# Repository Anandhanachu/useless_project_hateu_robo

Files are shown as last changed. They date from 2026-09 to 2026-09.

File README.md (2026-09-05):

git (1)

# HateBot 🤖😤

> *The utterly useless judgmental robot that exists purely to make you regret touching it.*

---

## Basic Details
### Team Name: Hateu_robo

### Project Description
HateBot sits on your desk, detects when you've disturbed it, and responds with maximum contempt — a disgusted face on screen, a dismissive arm flick, an annoyed buzz, and a mood LED that escalates from "tolerating you" to "furious." The joke is the point: massive engineering effort, zero useful output.

### The Problem (that doesn't exist)
Nobody asked for a robot that hates them. Desktop robots are usually friendly and helpful. This is wrong.

### The Solution (that nobody asked for)
A robot with a full emotional state machine calibrated entirely around contempt. The more you bother it, the angrier it gets, until it eventually gives up on you entirely and sulks in silence.

---

## Mood State Machine

```
        [idle sigh]
            |
        (IMU: small tilt) ──> ANNOYED ──(more disturbance)──> FURIOUS
            |                     |                               |
      (no input, 12s)       (no input, 10s)               (no input, 30s)
            |                     |                               |
            v                     v                               v
          CALM  <──────────────────────────────────────────── SULKING
                                                          (after 3 FURIOUS hits)
```

| Mood | LED | Face | Arms | Sound |
|---|---|---|---|---|
| **CALM** | 🟢 slow pulse | Bored slits, flat mouth | Occasional slow twitch | Rare low "hmph" |
| **ANNOYED** | 🟡 solid | Side-eye, angled brows | Quick synchronized flick | Two-tone descending "eh-eh" |
| **FURIOUS** | 🔴 blinking | Hard squint, V-brows, bared teeth | Rapid alternating flap x4 | Rising buzz sequence |
| **SULKING** | 🔴 slow blink | X eyes, resigned mouth | Raise & hold ("stop" pose) | One long low tone, then silence |

---

## Bill of Materials

| Component | Notes |
|---|---|
| NodeMCU ESP8266 | Microcontroller |
| TFT Display (ST7735, 1.8" SPI) | Face + insult text |
| IMU (MPU6050 I2C) | Detects tilt, shake, pickup, tap |
| Passive Buzzer | Emotional tones via PWM |
| 2× Micro Servo (SG90) | Arms — dismissive gestures |
| Single Green LED + Resistor | Mood indicator blinker |
| 5V Buck Converter | Servos + display need external power |
| Breadboard / perfboard, wires | Build |
| 3D Printed Enclosure | `hateu_pod.scad` — see `/hateu_pod.scad` |

> ⚠️ **Power Note:** Servos need their own 5V rail. Share only common ground with the ESP8266. Running servos off the ESP8266 3.3V will brown-out the microcontroller.

---

## Pin Mapping (ESP8266)

| Component | Signal | NodeMCU Pin | GPIO |
|---|---|---|---|
| **TFT ST7735** | SCK | D5 | 14 |
| | MOSI | D7 | 13 |
| | CS | D3 | 0 |
| | DC / A0 | D4 | 2 |
| | RESET | D0 | 16 |
| **MPU6050** | SDA | D2 | 4 |
| | SCL | D1 | 5 |
| **Servos** | Left Arm | D6 | 12 |
| | Right Arm | D8 | 15 |
| **Output** | Buzzer | TX | 1 |
| | Green LED | RX | 3 |

---

## IMU Interaction Detection

Reads at ~30 Hz, classifies events:

| Event | Detection | Mood Weight |
|---|---|---|
| **Tap / Knock** | High-pass acceleration spike | +1 |
| **Tilt** | Static angle > 15° from resting baseline | +1 |
| **Shake** | Rolling 8-sample variance spike | +2 |
| **Pickup** | Z-accel departs >0.3g for >500ms | +3 |

Picking it up is the fastest way to make it furious.

---

## Technical Details

### Software
- **Language:** C++ (Arduino framework for ESP8266)
- **Libraries:**
  - `Adafruit_ST7735` — TFT display
  - `Adafruit_GFX` — graphics primitives
  - `Servo` — standard ESP8266 servo library
  - `MPU6050` by Electronic Cats — IMU
  - `Wire`, `SPI` — built-in

---

## Installation

```bash
# 1. Install Arduino IDE 2.x
# 2. Add ESP8266 board package via Boards Manager
# 3. Install libraries via Library Manager:
#    - Adafruit ST7735 and ST7789 Library
#    - Adafruit GFX Library
#    - MPU6050 by Electronic Cats
# 4. Open firmware/hatebot/hatebot.ino
# 5. Select board: "NodeMCU 1.0 (ESP-12E Module)"
# 6. Upload
```

---

## Project Documentation

### Displays & UI
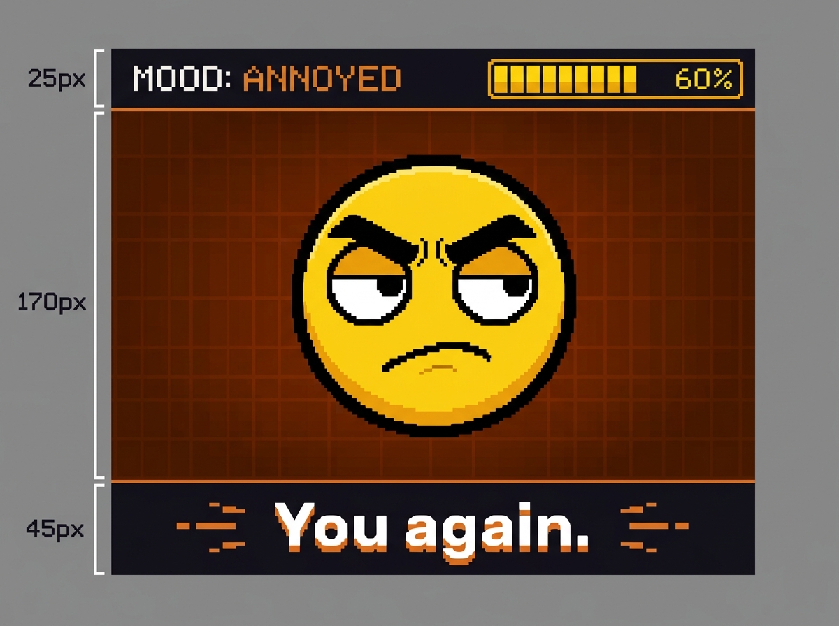
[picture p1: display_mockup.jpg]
HateBot Display Mockup

*Procedural face engine and typewriter text bar*

### Schematic & Circuit (Mermaid)

```mermaid
graph TD
    Power[5V Power Supply] --> Buck[5V Buck Converter]
    Buck -->|5V| NodeMCU[ESP8266 NodeMCU]
    Buck -->|5V| Servo1[Left Servo SG90]
    Buck -->|5V| Servo2[Right Servo SG90]
    
    NodeMCU -->|GND Common| Buck
    
    NodeMCU -->|D5 SCK| TFT[ST7735 TFT]
    NodeMCU -->|D7 MOSI| TFT
    NodeMCU -->|D3 CS| TFT
    NodeMCU -->|D4 DC| TFT
    NodeMCU -->|D0 RST| TFT
    
    NodeMCU -->|D2 SDA| MPU[MPU6050 IMU]
    NodeMCU -->|D1 SCL| MPU
    
    NodeMCU -->|D6 PWM| Servo1
    NodeMCU -->|D8 PWM| Servo2
    
    NodeMCU -->|TX| Buzzer[Passive Buzzer]
    NodeMCU -->|RX| LED[Green Status LED]
```

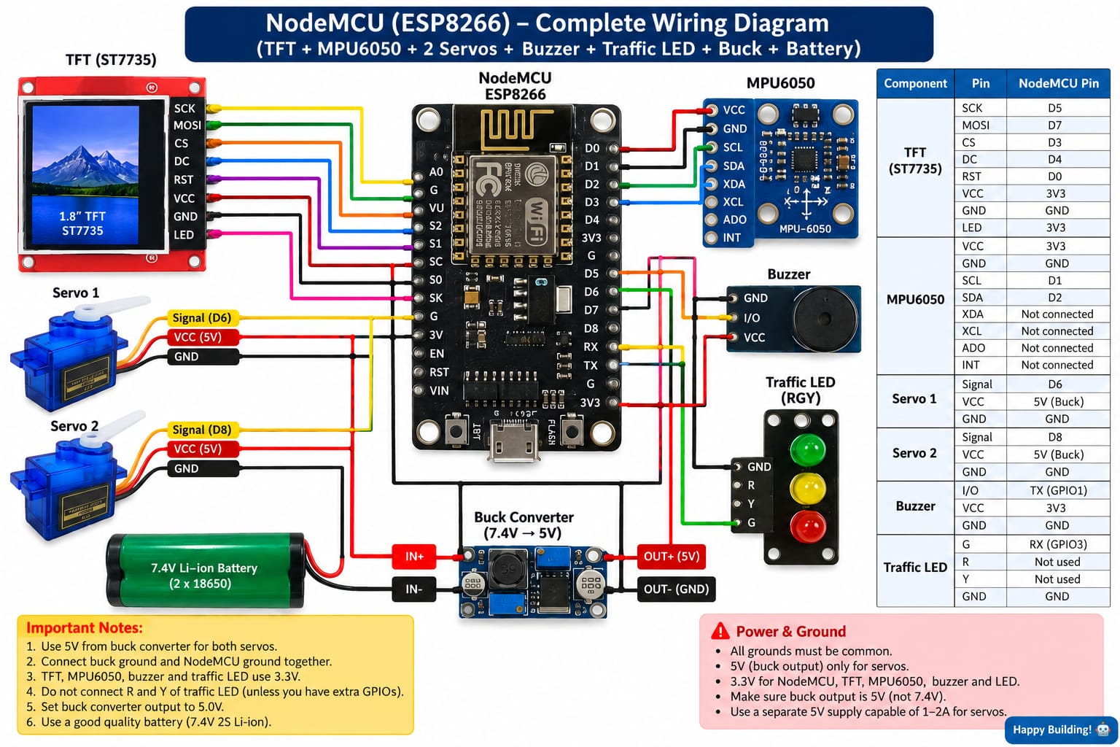
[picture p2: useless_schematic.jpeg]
Physical Schematic

*Hardware wiring overview*

### Build Photos
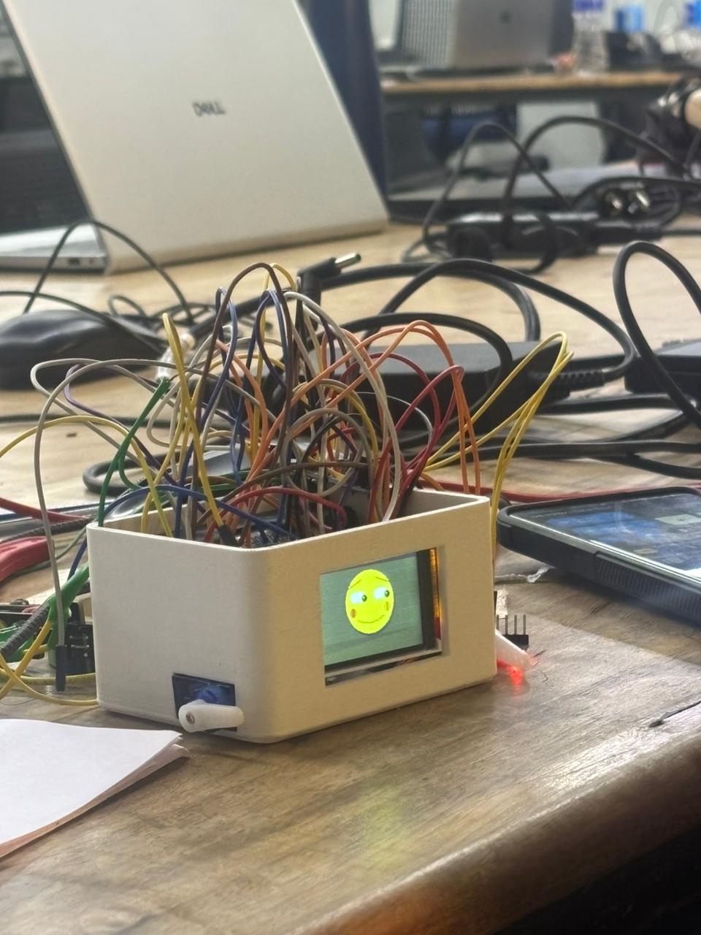
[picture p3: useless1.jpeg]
Final HateBot Build

*The final assembled HateBot*

---

## Roadmap of Uselessness (optional extensions)

- [ ] Light sensor — complains about room lighting
- [ ] Microphone — react to being yelled at
- [ ] "Forgiveness" gesture — hold level for 10s → rare, begrudging compliment

---

## Team Contributions
- **Anandhan**: Software and hardware integration
- **bhagath**: Hardware and 3D printing

---
Made with ❤️ at TinkerHub Useless Projects




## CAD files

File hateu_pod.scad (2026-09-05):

// ============================================================
//                 HATEU POD - FINAL V3 (Servo Edition)
// ============================================================

$fn = 48;

// ============================================================
// MAIN POD DIMENSIONS
// ============================================================

BOX_L = 90;
BOX_W = 70;
BOX_H = 50;

WALL = 3;
BOTTOM = 3;

CORNER_RADIUS = 7;

// ============================================================
// LID
// ============================================================

LID_TOP_THICKNESS = 3;
LID_LIP_HEIGHT = 5;
LID_LIP_THICKNESS = 2;
LID_CLEARANCE = 0.35;

// ============================================================
// TFT DISPLAY
// ============================================================

DISPLAY_L = 45;
DISPLAY_H = 30;
DISPLAY_BOTTOM = 11;

// ============================================================
// SERVO HOLE
// ============================================================
// Standard SG90 servo body is ~23 x 12.2 mm. 
// Added slight clearance.
SERVO_HOLE_L = 23.5;
SERVO_HOLE_W = 12.5;

// ============================================================
// USB CABLE HOLE
// ============================================================
USB_HOLE_W = 12;
USB_HOLE_H = 7;

// ============================================================
// CORNER MOUNTING BOSSES
// ============================================================

BOSS_RADIUS = 3.5;
BOSS_HEIGHT = 7;
BOSS_HOLE_RADIUS = 1.6;
BOSS_OFFSET = 8;

// ============================================================
// ROUNDED BOX
// ============================================================

module rounded_box(L, W, H, R) {
    // E is the edge rounding (fillet) for top/bottom edges. 
    // It makes the box look elegant without ruining wall thickness.
    E = min(2.5, H/2.001);
    
    // Ensure R is at least E to prevent scaling issues
    R_eff = max(R, E); 
    
    hull() {
        for(x = [R_eff, L-R_eff]) {
            for(y = [R_eff, W-R_eff]) {
                for(z = [E, H-E]) {
                    translate([x, y, z]) scale([R_eff/E, R_eff/E, 1]) sphere(r=E);
                }
            }
        }
    }
}

// ============================================================
// INTERNAL HOLLOW SPACE
// ============================================================

module inner_space() {
    translate([WALL, WALL, BOTTOM]) {
        rounded_box(BOX_L - 2*WALL, BOX_W - 2*WALL, BOX_H + 5, CORNER_RADIUS - WALL);
    }
}

// ============================================================
// TFT DISPLAY OPENING
// ============================================================

module display_opening() {
    translate([(BOX_L - DISPLAY_L)/2, -1, DISPLAY_BOTTOM]) {
        cube([DISPLAY_L, WALL + 2, DISPLAY_H]);
    }
}

// ============================================================
// SERVO SIDE HOLES
// ============================================================

module side_servo_holes() {
    // Cutout on Left and Right sides near the front display (Y=0) and bottom (Z=0)
    // Placed at Y=10 to clear the rounded corners
    
    // Left side hole
    translate([-1, 10, BOTTOM]) {
        cube([WALL + 2, SERVO_HOLE_L, SERVO_HOLE_W]);
    }
    
    // Right side hole
    translate([BOX_L - WALL - 1, 10, BOTTOM]) {
        cube([WALL + 2, SERVO_HOLE_L, SERVO_HOLE_W]);
    }
}

// ============================================================
// USB CABLE HOLE
// ============================================================

module usb_hole() {
    // Cutout on the back wall (Y = BOX_W) near the left corner (X=10) at bottom (Z=BOTTOM)
    translate([10, BOX_W - WALL - 1, BOTTOM]) {
        cube([USB_HOLE_W, WALL + 2, USB_HOLE_H]);
    }
}

// ============================================================
// MOUNTING BOSS
// ============================================================

module mounting_boss(x,y) {
    difference() {
        translate([x, y, BOTTOM]) cylinder(r=BOSS_RADIUS, h=BOSS_HEIGHT);
        translate([x, y, BOTTOM-1]) cylinder(r=BOSS_HOLE_RADIUS, h=BOSS_HEIGHT+2);
    }
}

// ============================================================
// FOUR CORNER BOSSES
// ============================================================

module mounting_bosses() {
    mounting_boss(BOSS_OFFSET, BOSS_OFFSET);
    mounting_boss(BOX_L-BOSS_OFFSET, BOSS_OFFSET);
    mounting_boss(BOSS_OFFSET, BOX_W-BOSS_OFFSET);
    mounting_boss(BOX_L-BOSS_OFFSET, BOX_W-BOSS_OFFSET);
}

// ============================================================
// FLAT TOP / BOTTOM ROUNDED BOXES
// ============================================================

module flat_top_rounded_box(L, W, H, R) {
    E = min(2.5, H/2.001);
    R_eff = max(R, E); 
    hull() {
        for(x = [R_eff, L-R_eff]) {
            for(y = [R_eff, W-R_eff]) {
                translate([x, y, E]) scale([R_eff/E, R_eff/E, 1]) sphere(r=E);
                translate([x, y, H - 0.01]) cylinder(r=R_eff, h=0.01);
            }
        }
    }
}

module flat_bottom_rounded_box(L, W, H, R) {
    E = min(2.5, H/2.001);
    R_eff = max(R, E); 
    hull() {
        for(x = [R_eff, L-R_eff]) {
            for(y = [R_eff, W-R_eff]) {
                translate([x, y, 0]) cylinder(r=R_eff, h=0.01);
                translate([x, y, H-E]) scale([R_eff/E, R_eff/E, 1]) sphere(r=E);
            }
        }
    }
}

// ============================================================
// MAIN POD BODY
// ============================================================

module main_pod() {
    difference() {
        // OUTER BODY (Flat top for flush lid fit)
        flat_top_rounded_box(BOX_L, BOX_W, BOX_H, CORNER_RADIUS);

        // OPEN INTERNAL AREA
        inner_space();

        // TFT
        display_opening();

        // SERVO HOLES
        side_servo_holes();

        // USB HOLE
        usb_hole();
    }
}

// ============================================================
// SEPARATE LID
// ============================================================

module rounded_prism(L, W, H, R) {
    R_eff = max(R, 0.001);
    linear_extrude(height = H) {
        hull() {
            translate([R_eff, R_eff]) circle(r=R_eff);
            translate([L-R_eff, R_eff]) circle(r=R_eff);
            translate([R_eff, W-R_eff]) circle(r=R_eff);
            translate([L-R_eff, W-R_eff]) circle(r=R_eff);
        }
    }
}

module lid() {
    // The top cover has a flush-fitting lip underneath.
    // The lip outer dimension exactly matches the inner space of the box minus clearance.
    difference() {
        union() {
            // TOP (Flat bottom for flush lip attachment and fit)
            flat_bottom_rounded_box(BOX_L, BOX_W, LID_TOP_THICKNESS, CORNER_RADIUS);

            // INNER LIP
            translate([WALL + LID_CLEARANCE, WALL + LID_CLEARANCE, -LID_LIP_HEIGHT]) {
                difference() {
                    // Outer lip boundary (fits into the hole)
                    rounded_prism(
                        BOX_L - 2*(WALL+LID_CLEARANCE),
                        BOX_W - 2*(WALL+LID_CLEARANCE),
                        LID_LIP_HEIGHT,
                        max(0, CORNER_RADIUS - WALL - LID_CLEARANCE)
                    );

                    // Inner lip hollow
                    translate([LID_LIP_THICKNESS, LID_LIP_THICKNESS, -1]) {
                        rounded_prism(
                            BOX_L - 2*(WALL+LID_CLEARANCE) - 2*LID_LIP_THICKNESS,
                            BOX_W - 2*(WALL+LID_CLEARANCE) - 2*LID_LIP_THICKNESS,
                            LID_LIP_HEIGHT+2,
                            max(0, CORNER_RADIUS - WALL - LID_CLEARANCE - LID_LIP_THICKNESS)
                        );
                    }
                }
            }
        }

        // 35mm x 13mm TOP MIDDLE HOLE
        translate([(BOX_L - 35)/2, (BOX_W - 13)/2, -1]) {
            cube([35, 13, LID_TOP_THICKNESS + 2]);
        }
    }
}

// ============================================================
// PRINT MODE
// ============================================================
// 1 = BODY ONLY
// 2 = LID ONLY
// 3 = BODY + LID
// ============================================================

PRINT_MODE = 3;

// ============================================================
// OUTPUT
// ============================================================

if(PRINT_MODE == 1) {
    main_pod();
}

if(PRINT_MODE == 2) {
    // Print flipped so flat top is on bed, lip points up
    translate([0, BOX_W, LID_TOP_THICKNESS]) rotate([180, 0, 0]) lid();
}

if(PRINT_MODE == 3) {
    main_pod();
    // Print flipped for support-free printing
    translate([BOX_L + 15, BOX_W, LID_TOP_THICKNESS]) rotate([180, 0, 0]) lid();
}

// ============================================================
//                       END
// ============================================================

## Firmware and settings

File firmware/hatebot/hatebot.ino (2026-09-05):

// ΓòöΓòÉΓòÉΓòÉΓòÉΓòÉΓòÉΓòÉΓòÉΓòÉΓòÉΓòÉΓòÉΓòÉΓòÉΓòÉΓòÉΓòÉΓòÉΓòÉΓòÉΓòÉΓòÉΓòÉΓòÉΓòÉΓòÉΓòÉΓòÉΓòÉΓòÉΓòÉΓòÉΓòÉΓòÉΓòÉΓòÉΓòÉΓòÉΓòÉΓòÉΓòÉΓòÉΓòÉΓòÉΓòÉΓòÉΓòÉΓòÉΓòÉΓòÉΓòÉΓòÉΓòÉΓòÉΓòÉΓòÉΓòÉΓòÉΓòÉΓòÉΓòÉΓòÉΓòù
// Γòæ      HateBot ΓÇö Firmware v3  |  Procedural Animation Engine  Γòæ
// Γòæ  ESP32 NodeMCU + ILI9341 320├ù240 + MPU6050 + 2├ùSG90        Γòæ
// ΓòÜΓòÉΓòÉΓòÉΓòÉΓòÉΓòÉΓòÉΓòÉΓòÉΓòÉΓòÉΓòÉΓòÉΓòÉΓòÉΓòÉΓòÉΓòÉΓòÉΓòÉΓòÉΓòÉΓòÉΓòÉΓòÉΓòÉΓòÉΓòÉΓòÉΓòÉΓòÉΓòÉΓòÉΓòÉΓòÉΓòÉΓòÉΓòÉΓòÉΓòÉΓòÉΓòÉΓòÉΓòÉΓòÉΓòÉΓòÉΓòÉΓòÉΓòÉΓòÉΓòÉΓòÉΓòÉΓòÉΓòÉΓòÉΓòÉΓòÉΓòÉΓòÉΓòÉΓò¥
//
//  ZERO bitmaps ΓÇö 100% procedural drawing.
//  All animations are math (sin/cos/lerp) + Adafruit_GFX primitives.
//  Compiled app fits well under 400KB ΓÇö safe for 4MB NodeMCU flash.
//
//  SCREEN LAYOUT (landscape 320├ù240)
//  ΓöîΓöÇΓöÇΓöÇΓöÇΓöÇΓöÇΓöÇΓöÇΓöÇΓöÇΓöÇΓöÇΓöÇΓöÇΓöÇΓöÇΓöÇΓöÇΓöÇΓöÇΓöÇΓöÇΓöÇΓöÇΓöÇΓöÇΓöÇΓöÇΓöÇΓöÇΓöÇΓöÇΓöÇΓöÇΓöÇΓöÇΓöÇΓöÇΓöÇΓöÇΓöÇΓöÇΓöÇΓöÇΓöÇΓöÇΓöÇΓöÇΓöÇΓöÉ y=0
//  Γöé  MOOD: FURIOUS       [ΓûêΓûêΓûêΓûêΓûêΓûêΓûêΓûêΓûêΓûê]  85%  ΓÖÑbeat   Γöé y=0ΓÇÑ24
//  Γö£ΓöÇΓöÇΓöÇΓöÇΓöÇΓöÇΓöÇΓöÇΓöÇΓöÇΓöÇΓöÇΓöÇΓöÇΓöÇΓöÇΓöÇΓöÇΓöÇΓöÇΓöÇΓöÇΓöÇΓöÇΓöÇΓöÇΓöÇΓöÇΓöÇΓöÇΓöÇΓöÇΓöÇΓöÇΓöÇΓöÇΓöÇΓöÇΓöÇΓöÇΓöÇΓöÇΓöÇΓöÇΓöÇΓöÇΓöÇΓöÇΓöÇΓöñ y=25
//  Γöé  ~~grid bg~~                                    Γöé
//  Γöé          Γò¡ΓöÇΓöÇΓöÇΓöÇΓöÇΓöÇΓöÇΓöÇΓöÇΓöÇΓò«                           Γöé
//  Γöé   steam  Γöé  (face)  Γöé  steam    <effects>       Γöé y=25ΓÇÑ194
//  Γöé   wisps  Γò░ΓöÇΓöÇΓöÇΓöÇΓöÇΓöÇΓöÇΓöÇΓöÇΓöÇΓò»                           Γöé
//  Γö£ΓöÇΓöÇΓöÇΓöÇΓöÇΓöÇΓöÇΓöÇΓöÇΓöÇΓöÇΓöÇΓöÇΓöÇΓöÇΓöÇΓöÇΓöÇΓöÇΓöÇΓöÇΓöÇΓöÇΓöÇΓöÇΓöÇΓöÇΓöÇΓöÇΓöÇΓöÇΓöÇΓöÇΓöÇΓöÇΓöÇΓöÇΓöÇΓöÇΓöÇΓöÇΓöÇΓöÇΓöÇΓöÇΓöÇΓöÇΓöÇΓöÇΓöñ y=195
//  Γöé  -=  "STOP. TOUCHING. ME."  =-                  Γöé y=195ΓÇÑ239
//  ΓööΓöÇΓöÇΓöÇΓöÇΓöÇΓöÇΓöÇΓöÇΓöÇΓöÇΓöÇΓöÇΓöÇΓöÇΓöÇΓöÇΓöÇΓöÇΓöÇΓöÇΓöÇΓöÇΓöÇΓöÇΓöÇΓöÇΓöÇΓöÇΓöÇΓöÇΓöÇΓöÇΓöÇΓöÇΓöÇΓöÇΓöÇΓöÇΓöÇΓöÇΓöÇΓöÇΓöÇΓöÇΓöÇΓöÇΓöÇΓöÇΓöÇΓöÿ

#include <SPI.h>
#include <Wire.h>
#include <Adafruit_GFX.h>
#include <Adafruit_ST7735.h>
#include <Servo.h>
#include <MPU6050.h>
#include <math.h>

// ΓòÉΓòÉΓòÉΓòÉΓòÉΓòÉΓòÉΓòÉΓòÉΓòÉΓòÉΓòÉΓòÉΓòÉΓòÉΓòÉΓòÉΓòÉΓòÉΓòÉΓòÉΓòÉΓòÉΓòÉΓòÉΓòÉΓòÉΓòÉΓòÉΓòÉΓòÉΓòÉΓòÉΓòÉΓòÉΓòÉΓòÉΓòÉΓòÉΓòÉΓòÉΓòÉΓòÉΓòÉΓòÉΓòÉΓòÉΓòÉΓòÉΓòÉΓòÉ
//  PINS
// ΓòÉΓòÉΓòÉΓòÉΓòÉΓòÉΓòÉΓòÉΓòÉΓòÉΓòÉΓòÉΓòÉΓòÉΓòÉΓòÉΓòÉΓòÉΓòÉΓòÉΓòÉΓòÉΓòÉΓòÉΓòÉΓòÉΓòÉΓòÉΓòÉΓòÉΓòÉΓòÉΓòÉΓòÉΓòÉΓòÉΓòÉΓòÉΓòÉΓòÉΓòÉΓòÉΓòÉΓòÉΓòÉΓòÉΓòÉΓòÉΓòÉΓòÉΓòÉ
#define TFT_CS   0
#define TFT_DC   2
#define TFT_RST  16
#define IMU_SDA  4
#define IMU_SCL  5
#define ARM_L    12
#define ARM_R    15
#define BUZZ     1
#define LED_G    3

// ΓòÉΓòÉΓòÉΓòÉΓòÉΓòÉΓòÉΓòÉΓòÉΓòÉΓòÉΓòÉΓòÉΓòÉΓòÉΓòÉΓòÉΓòÉΓòÉΓòÉΓòÉΓòÉΓòÉΓòÉΓòÉΓòÉΓòÉΓòÉΓòÉΓòÉΓòÉΓòÉΓòÉΓòÉΓòÉΓòÉΓòÉΓòÉΓòÉΓòÉΓòÉΓòÉΓòÉΓòÉΓòÉΓòÉΓòÉΓòÉΓòÉΓòÉΓòÉ
//  SCREEN CONSTANTS
// ΓòÉΓòÉΓòÉΓòÉΓòÉΓòÉΓòÉΓòÉΓòÉΓòÉΓòÉΓòÉΓòÉΓòÉΓòÉΓòÉΓòÉΓòÉΓòÉΓòÉΓòÉΓòÉΓòÉΓòÉΓòÉΓòÉΓòÉΓòÉΓòÉΓòÉΓòÉΓòÉΓòÉΓòÉΓòÉΓòÉΓòÉΓòÉΓòÉΓòÉΓòÉΓòÉΓòÉΓòÉΓòÉΓòÉΓòÉΓòÉΓòÉΓòÉΓòÉ
#define SW      160
#define SH      128
#define TB_H    14          // top bar height
#define IB_Y    104         // insult bar top
#define FA_Y    TB_H        // face area top
#define FA_H    (IB_Y-TB_H) // face area height = 170
#define FCX     160         // face center X
#define FCY     (TB_H + FA_H/2)   // face center Y = 110
#define FR      28          // face base radius

// ΓòÉΓòÉΓòÉΓòÉΓòÉΓòÉΓòÉΓòÉΓòÉΓòÉΓòÉΓòÉΓòÉΓòÉΓòÉΓòÉΓòÉΓòÉΓòÉΓòÉΓòÉΓòÉΓòÉΓòÉΓòÉΓòÉΓòÉΓòÉΓòÉΓòÉΓòÉΓòÉΓòÉΓòÉΓòÉΓòÉΓòÉΓòÉΓòÉΓòÉΓòÉΓòÉΓòÉΓòÉΓòÉΓòÉΓòÉΓòÉΓòÉΓòÉΓòÉ
//  COLOURS  (RGB565)
// ΓòÉΓòÉΓòÉΓòÉΓòÉΓòÉΓòÉΓòÉΓòÉΓòÉΓòÉΓòÉΓòÉΓòÉΓòÉΓòÉΓòÉΓòÉΓòÉΓòÉΓòÉΓòÉΓòÉΓòÉΓòÉΓòÉΓòÉΓòÉΓòÉΓòÉΓòÉΓòÉΓòÉΓòÉΓòÉΓòÉΓòÉΓòÉΓòÉΓòÉΓòÉΓòÉΓòÉΓòÉΓòÉΓòÉΓòÉΓòÉΓòÉΓòÉΓòÉ
#define C_BLK   0x0000
#define C_WHT   0xFFFF
#define C_FACE  0xFEA0   // warm yellow
#define C_SHAD  0xB580   // face shadow
#define C_BLUSH 0xF810   // cheek blush
#define C_TEAR  0x035F   // tear blue
#define C_TRHGL 0x07FF   // tear highlight
#define C_STEAM 0xBDD7   // steam grey-white
#define C_VEIN  0xF800   // forehead vein red
#define C_ZZZ   0x07E0   // calm ZZZ green-teal
#define C_LGTN  0xFFE0   // lightning yellow

// BG per mood
#define BG_CLM  0x0228
#define BG_ANN  0x2100
#define BG_FUR  0x3800
#define BG_SUL  0x100A

// Grid per mood
#define GR_CLM  0x0430
#define GR_ANN  0x3180
#define GR_FUR  0x5000
#define GR_SUL  0x180C

// Rage colours
#define RC_CLM  0x07E0
#define RC_ANN  0xFD20
#define RC_FUR  0xF800
#define RC_SUL  0x780F

// Text colours
#define TC_CLM  0x67FE
#define TC_ANN  0xFD20
#define TC_FUR  0xF81F
#define TC_SUL  0x8C71

// Bar chrome
#define C_BARBG 0x0841
#define C_BRBRD 0x4208

// ΓòÉΓòÉΓòÉΓòÉΓòÉΓòÉΓòÉΓòÉΓòÉΓòÉΓòÉΓòÉΓòÉΓòÉΓòÉΓòÉΓòÉΓòÉΓòÉΓòÉΓòÉΓòÉΓòÉΓòÉΓòÉΓòÉΓòÉΓòÉΓòÉΓòÉΓòÉΓòÉΓòÉΓòÉΓòÉΓòÉΓòÉΓòÉΓòÉΓòÉΓòÉΓòÉΓòÉΓòÉΓòÉΓòÉΓòÉΓòÉΓòÉΓòÉΓòÉ
//  MOOD STATE MACHINE
// ΓòÉΓòÉΓòÉΓòÉΓòÉΓòÉΓòÉΓòÉΓòÉΓòÉΓòÉΓòÉΓòÉΓòÉΓòÉΓòÉΓòÉΓòÉΓòÉΓòÉΓòÉΓòÉΓòÉΓòÉΓòÉΓòÉΓòÉΓòÉΓòÉΓòÉΓòÉΓòÉΓòÉΓòÉΓòÉΓòÉΓòÉΓòÉΓòÉΓòÉΓòÉΓòÉΓòÉΓòÉΓòÉΓòÉΓòÉΓòÉΓòÉΓòÉΓòÉ
enum Mood { CALM=0, ANNOYED=1, FURIOUS=2, SULKING=3 };
Mood   mood          = CALM;
int    furiousHits   = 0;
#define SULK_AT       3
unsigned long quietMs = 0;
unsigned long lastEvt = 0;
#define T_ANN_CLM   12000UL
#define T_FUR_ANN   10000UL
#define T_SUL_CLM   30000UL

// ΓòÉΓòÉΓòÉΓòÉΓòÉΓòÉΓòÉΓòÉΓòÉΓòÉΓòÉΓòÉΓòÉΓòÉΓòÉΓòÉΓòÉΓòÉΓòÉΓòÉΓòÉΓòÉΓòÉΓòÉΓòÉΓòÉΓòÉΓòÉΓòÉΓòÉΓòÉΓòÉΓòÉΓòÉΓòÉΓòÉΓòÉΓòÉΓòÉΓòÉΓòÉΓòÉΓòÉΓòÉΓòÉΓòÉΓòÉΓòÉΓòÉΓòÉΓòÉ
//  FACE PARAMETER SYSTEM  (lerped every frame)
// ΓòÉΓòÉΓòÉΓòÉΓòÉΓòÉΓòÉΓòÉΓòÉΓòÉΓòÉΓòÉΓòÉΓòÉΓòÉΓòÉΓòÉΓòÉΓòÉΓòÉΓòÉΓòÉΓòÉΓòÉΓòÉΓòÉΓòÉΓòÉΓòÉΓòÉΓòÉΓòÉΓòÉΓòÉΓòÉΓòÉΓòÉΓòÉΓòÉΓòÉΓòÉΓòÉΓòÉΓòÉΓòÉΓòÉΓòÉΓòÉΓòÉΓòÉΓòÉ
struct FP {
  float eyeOpen;    // 0=closed .. 1=fully open
  float browAngle;  // 0=flat, +ve=angry V, -ve=sad arch
  float browH;      // eyebrow vertical offset (px)
  float pupilX;     // -1=far left .. +1=far right
  float pupilY;     // -1=up .. +1=down
  float mouth;      // -1=big frown .. 0=flat .. +1=smile
};

// Current (lerped toward target)
FP cur  = {0.8f, 0.0f, 0.0f, 0.0f, 0.0f, -0.1f};

// Targets per mood
const FP tgt[4] = {
//  eyeO  browA  browH  pupX   pupY   mouth
  { 0.55f,  0.0f, -2.0f,  0.0f,  0.0f, -0.15f }, // CALM
  { 0.85f, 22.0f, -5.0f, -0.75f, 0.0f, -0.55f }, // ANNOYED
  { 0.30f, 40.0f,-10.0f,  0.0f,  0.2f, -0.85f }, // FURIOUS
  { 0.90f,  5.0f,  8.0f,  0.0f,  0.3f, -0.05f }, // SULKING
};

inline float lerp(float a, float b, float t) { return a + (b-a)*t; }
#define LERP_SPEED  0.12f   // per frame at 30Hz

// ΓòÉΓòÉΓòÉΓòÉΓòÉΓòÉΓòÉΓòÉΓòÉΓòÉΓòÉΓòÉΓòÉΓòÉΓòÉΓòÉΓòÉΓòÉΓòÉΓòÉΓòÉΓòÉΓòÉΓòÉΓòÉΓòÉΓòÉΓòÉΓòÉΓòÉΓòÉΓòÉΓòÉΓòÉΓòÉΓòÉΓòÉΓòÉΓòÉΓòÉΓòÉΓòÉΓòÉΓòÉΓòÉΓòÉΓòÉΓòÉΓòÉΓòÉΓòÉ
//  ANIMATION STATE
// ΓòÉΓòÉΓòÉΓòÉΓòÉΓòÉΓòÉΓòÉΓòÉΓòÉΓòÉΓòÉΓòÉΓòÉΓòÉΓòÉΓòÉΓòÉΓòÉΓòÉΓòÉΓòÉΓòÉΓòÉΓòÉΓòÉΓòÉΓòÉΓòÉΓòÉΓòÉΓòÉΓòÉΓòÉΓòÉΓòÉΓòÉΓòÉΓòÉΓòÉΓòÉΓòÉΓòÉΓòÉΓòÉΓòÉΓòÉΓòÉΓòÉΓòÉΓòÉ
uint32_t frame       = 0;    // global frame counter
uint32_t loopMs      = 33;   // ~30 Hz

// Eye blink
unsigned long blinkAt  = 0;
bool          blinking = false;
unsigned long blinkMs  = 0;
#define BLINK_DUR  110UL

// Typewriter
char          insultBuf[34] = "";
uint8_t       revealed = 0;
unsigned long twMs     = 0;
#define TW_SPD  52UL

// Rage meter heartbeat
uint8_t  ragePct     = 10;   // displayed value (animated)
uint8_t  rageTarget  = 10;
unsigned long rageMs = 0;
#define RAGE_STEP  25UL
bool     hbFlash     = false;
unsigned long hbMs   = 0;
#define HB_INTERVAL 500UL

// Screen shake  (FURIOUS)
int8_t shX=0, shY=0;
unsigned long shakeMs = 0;
#define SHAKE_SPD 70UL

// ZZZ particles  (CALM)
struct Zzz { int16_t x, y; uint8_t alpha; };
Zzz zzzP[3];
unsigned long zzzMs = 0;
#define ZZZ_SPD 200UL

// Steam wisps  (FURIOUS)
struct Steam { int16_t y; uint8_t r; bool active; };
Steam stmL[4], stmR[4];
unsigned long stmMs = 0;
#define STM_SPD 120UL

// Tear drop  (SULKING)
int16_t tearY = 0;
bool    tearActive = false;
unsigned long tearMs = 0;
#define TEAR_SPD 80UL

// Sweat bead  (SULKING/ANNOYED)
int16_t sweatY = 0;
unsigned long sweatMs = 0;

// Pupil jitter  (ANNOYED)
float pjX=0, pjY=0;
unsigned long pjMs = 0;

// Border lightning  (FURIOUS)
unsigned long lgtMs = 0;
bool lgtOn = false;
#define LGT_SPD 250UL

// Eyebrow twitch  (ANNOYED)
float browTwitch = 0.0f;
unsigned long btMs  = 0;
#define BT_SPD 60UL

// LED blink
unsigned long ledMs = 0;
bool ledBlink = false;

// Mood change flash
unsigned long flashMs = 0;
bool flashing = false;
uint16_t flashCol = 0;

// Idle arm
unsigned long idleArmMs = 0;
#define IDLE_ARM 9000UL

// ΓòÉΓòÉΓòÉΓòÉΓòÉΓòÉΓòÉΓòÉΓòÉΓòÉΓòÉΓòÉΓòÉΓòÉΓòÉΓòÉΓòÉΓòÉΓòÉΓòÉΓòÉΓòÉΓòÉΓòÉΓòÉΓòÉΓòÉΓòÉΓòÉΓòÉΓòÉΓòÉΓòÉΓòÉΓòÉΓòÉΓòÉΓòÉΓòÉΓòÉΓòÉΓòÉΓòÉΓòÉΓòÉΓòÉΓòÉΓòÉΓòÉΓòÉΓòÉ
//  STRING POOLS (PROGMEM saves RAM)
// ΓòÉΓòÉΓòÉΓòÉΓòÉΓòÉΓòÉΓòÉΓòÉΓòÉΓòÉΓòÉΓòÉΓòÉΓòÉΓòÉΓòÉΓòÉΓòÉΓòÉΓòÉΓòÉΓòÉΓòÉΓòÉΓòÉΓòÉΓòÉΓòÉΓòÉΓòÉΓòÉΓòÉΓòÉΓòÉΓòÉΓòÉΓòÉΓòÉΓòÉΓòÉΓòÉΓòÉΓòÉΓòÉΓòÉΓòÉΓòÉΓòÉΓòÉΓòÉ
const char s_c0[] PROGMEM = "Oh. It's you.";
const char s_c1[] PROGMEM = "Still here?";
const char s_c2[] PROGMEM = "...cool.";
const char s_c3[] PROGMEM = "Ugh.";
const char s_c4[] PROGMEM = "Whatever.";
const char s_c5[] PROGMEM = "Fine. Hi.";
const char* const pool_calm[] PROGMEM = {s_c0,s_c1,s_c2,s_c3,s_c4,s_c5};

const char s_a0[] PROGMEM = "Seriously?";
const char s_a1[] PROGMEM = "I'm busy existing.";
const char s_a2[] PROGMEM = "Please stop.";
const char s_a3[] PROGMEM = "You again.";
const char s_a4[] PROGMEM = "Not now.";
const char s_a5[] PROGMEM = "Oh come ON.";
const char s_a6[] PROGMEM = "Excuse you.";
const char* const pool_ann[] PROGMEM  = {s_a0,s_a1,s_a2,s_a3,s_a4,s_a5,s_a6};

const char s_f0[] PROGMEM = "HOW DARE YOU.";
const char s_f1[] PROGMEM = "I HAVE HAD IT.";
const char s_f2[] PROGMEM = "STOP.TOUCHING.ME.";
const char s_f3[] PROGMEM = "PERSONAL SPACE!";
const char s_f4[] PROGMEM = "ABSOLUTELY NOT.";
const char s_f5[] PROGMEM = "GET. AWAY.";
const char* const pool_fur[] PROGMEM  = {s_f0,s_f1,s_f2,s_f3,s_f4,s_f5};

const char s_s0[] PROGMEM = "I'm done.";
const char s_s1[] PROGMEM = "Talk to the hand.";
const char s_s2[] PROGMEM = "...";
const char s_s3[] PROGMEM = "Goodbye.";
const char* const pool_sul[] PROGMEM  = {s_s0,s_s1,s_s2,s_s3};

const uint8_t poolSz[4] = {6, 7, 6, 4};
uint8_t insultIdx[4]    = {0, 0, 0, 0};
const uint8_t rTgt[4]   = {10, 45, 85, 28}; // rage % per mood

// ΓòÉΓòÉΓòÉΓòÉΓòÉΓòÉΓòÉΓòÉΓòÉΓòÉΓòÉΓòÉΓòÉΓòÉΓòÉΓòÉΓòÉΓòÉΓòÉΓòÉΓòÉΓòÉΓòÉΓòÉΓòÉΓòÉΓòÉΓòÉΓòÉΓòÉΓòÉΓòÉΓòÉΓòÉΓòÉΓòÉΓòÉΓòÉΓòÉΓòÉΓòÉΓòÉΓòÉΓòÉΓòÉΓòÉΓòÉΓòÉΓòÉΓòÉΓòÉ
//  COLOUR HELPERS
// ΓòÉΓòÉΓòÉΓòÉΓòÉΓòÉΓòÉΓòÉΓòÉΓòÉΓòÉΓòÉΓòÉΓòÉΓòÉΓòÉΓòÉΓòÉΓòÉΓòÉΓòÉΓòÉΓòÉΓòÉΓòÉΓòÉΓòÉΓòÉΓòÉΓòÉΓòÉΓòÉΓòÉΓòÉΓòÉΓòÉΓòÉΓòÉΓòÉΓòÉΓòÉΓòÉΓòÉΓòÉΓòÉΓòÉΓòÉΓòÉΓòÉΓòÉΓòÉ
uint16_t bgC(Mood m)  { const uint16_t t[]={BG_CLM,BG_ANN,BG_FUR,BG_SUL}; return t[m]; }
uint16_t grC(Mood m)  { const uint16_t t[]={GR_CLM,GR_ANN,GR_FUR,GR_SUL}; return t[m]; }
uint16_t rcC(Mood m)  { const uint16_t t[]={RC_CLM,RC_ANN,RC_FUR,RC_SUL}; return t[m]; }
uint16_t tcC(Mood m)  { const uint16_t t[]={TC_CLM,TC_ANN,TC_FUR,TC_SUL}; return t[m]; }
const char* moodStr(Mood m){ const char* t[]={"CALM","ANNOYED","FURIOUS","SULKING"}; return t[m]; }

// ΓòÉΓòÉΓòÉΓòÉΓòÉΓòÉΓòÉΓòÉΓòÉΓòÉΓòÉΓòÉΓòÉΓòÉΓòÉΓòÉΓòÉΓòÉΓòÉΓòÉΓòÉΓòÉΓòÉΓòÉΓòÉΓòÉΓòÉΓòÉΓòÉΓòÉΓòÉΓòÉΓòÉΓòÉΓòÉΓòÉΓòÉΓòÉΓòÉΓòÉΓòÉΓòÉΓòÉΓòÉΓòÉΓòÉΓòÉΓòÉΓòÉΓòÉΓòÉ
//  HARDWARE
// ΓòÉΓòÉΓòÉΓòÉΓòÉΓòÉΓòÉΓòÉΓòÉΓòÉΓòÉΓòÉΓòÉΓòÉΓòÉΓòÉΓòÉΓòÉΓòÉΓòÉΓòÉΓòÉΓòÉΓòÉΓòÉΓòÉΓòÉΓòÉΓòÉΓòÉΓòÉΓòÉΓòÉΓòÉΓòÉΓòÉΓòÉΓòÉΓòÉΓòÉΓòÉΓòÉΓòÉΓòÉΓòÉΓòÉΓòÉΓòÉΓòÉΓòÉΓòÉ
Adafruit_ST7735 tft(TFT_CS, TFT_DC, TFT_RST);
MPU6050 imu;
Servo   sL, sR;

float bAx,bAy,bAz;
float prevHP=0;
bool  inPick=false;
unsigned long pickMs=0;
#define IMU_CAL  150
#define SH_VAR   500000.0f
#define TILT_DEG 14.0f
#define PICK_G   0.28f
#define PICK_MS  480
#define TAP_HP   2000.0f

// ΓòÉΓòÉΓòÉΓòÉΓòÉΓòÉΓòÉΓòÉΓòÉΓòÉΓòÉΓòÉΓòÉΓòÉΓòÉΓòÉΓòÉΓòÉΓòÉΓòÉΓòÉΓòÉΓòÉΓòÉΓòÉΓòÉΓòÉΓòÉΓòÉΓòÉΓòÉΓòÉΓòÉΓòÉΓòÉΓòÉΓòÉΓòÉΓòÉΓòÉΓòÉΓòÉΓòÉΓòÉΓòÉΓòÉΓòÉΓòÉΓòÉΓòÉΓòÉ
//  FORWARD DECLARATIONS
// ΓòÉΓòÉΓòÉΓòÉΓòÉΓòÉΓòÉΓòÉΓòÉΓòÉΓòÉΓòÉΓòÉΓòÉΓòÉΓòÉΓòÉΓòÉΓòÉΓòÉΓòÉΓòÉΓòÉΓòÉΓòÉΓòÉΓòÉΓòÉΓòÉΓòÉΓòÉΓòÉΓòÉΓòÉΓòÉΓòÉΓòÉΓòÉΓòÉΓòÉΓòÉΓòÉΓòÉΓòÉΓòÉΓòÉΓòÉΓòÉΓòÉΓòÉΓòÉ
void calIMU();
int  evIMU();
void escalate(int w);
void deEscalate();
void changeMood(Mood m);
void react(Mood m);
void startInsult(Mood m);
void fetchInsult(Mood m, char* buf, uint8_t sz);

// Display
void drawAll();
void drawBG(int8_t ox=0, int8_t oy=0);
void drawTopBar();
void drawRage(uint8_t pct, bool hb=false);
void drawInsultBar();
void drawInsultText(uint8_t chars);
void drawFace(int8_t ox=0, int8_t oy=0);
void drawEyes(int cx, int cy);
void drawBrows(int cx, int cy);
void drawMouth(int cx, int cy);
void drawFxCalm(int cx, int cy);
void drawFxAnnoyed(int cx, int cy);
void drawFxFurious(int cx, int cy);
void drawFxSulking(int cx, int cy);
void drawLightning();
void flashScreen(uint16_t col, int ms);

// Helpers
void drawMouthCurve(int cx, int cy, float curve, uint16_t col, int thick=2);
void drawThickLine(int x0,int y0,int x1,int y1,int t,uint16_t c);
void armGo(int l, int r, int ms);
void buzz(int f, int d);
void buzzPat(Mood m);
void setLED(Mood m);
void initSteam();
void initZzz();

// ΓòÉΓòÉΓòÉΓòÉΓòÉΓòÉΓòÉΓòÉΓòÉΓòÉΓòÉΓòÉΓòÉΓòÉΓòÉΓòÉΓòÉΓòÉΓòÉΓòÉΓòÉΓòÉΓòÉΓòÉΓòÉΓòÉΓòÉΓòÉΓòÉΓòÉΓòÉΓòÉΓòÉΓòÉΓòÉΓòÉΓòÉΓòÉΓòÉΓòÉΓòÉΓòÉΓòÉΓòÉΓòÉΓòÉΓòÉΓòÉΓòÉΓòÉΓòÉ
//  SETUP
// ΓòÉΓòÉΓòÉΓòÉΓòÉΓòÉΓòÉΓòÉΓòÉΓòÉΓòÉΓòÉΓòÉΓòÉΓòÉΓòÉΓòÉΓòÉΓòÉΓòÉΓòÉΓòÉΓòÉΓòÉΓòÉΓòÉΓòÉΓòÉΓòÉΓòÉΓòÉΓòÉΓòÉΓòÉΓòÉΓòÉΓòÉΓòÉΓòÉΓòÉΓòÉΓòÉΓòÉΓòÉΓòÉΓòÉΓòÉΓòÉΓòÉΓòÉΓòÉ
void setup() {
  Serial.begin(115200);

  // TFT boot
  
  tft.initR(INITR_BLACKTAB); tft.setSPISpeed(40000000); tft.setRotation(1);
  tft.fillScreen(C_BLK);

  // Boot splash ΓÇö minimal, fast
  tft.setTextSize(1); tft.setTextColor(TC_CLM);
  tft.setCursor(28, 44); tft.print("HateBot v3.0");
  tft.setTextSize(1); tft.setTextColor(TC_SUL);
  tft.setCursor(38, 57); tft.print("Procedural Edition");
  tft.setCursor(44, 70); tft.print("calibrating...");
  buzz(220,70); delay(80); buzz(330,70); delay(80); buzz(520,120);

  // Hardware
  pinMode(LED_G,OUTPUT); 
  pinMode(BUZZ,OUTPUT);
  sL.attach(ARM_L); sR.attach(ARM_R);
  armGo(90,90,500);

  Wire.begin(IMU_SDA,IMU_SCL);
  imu.initialize();
  if(!imu.testConnection()) Serial.println("[WARN] IMU not found");
  calIMU();

  // Init animations
  initZzz();
  initSteam();
  tearY  = FCY - FR/2;
  sweatY = FCY - FR/3;

  // First draw
  rageTarget = rTgt[CALM];
  drawAll();
  setLED(CALM);
  startInsult(CALM);

  blinkAt    = millis() + random(3000,6000);
  lastEvt    = millis();
  idleArmMs  = millis();
}

// ΓòÉΓòÉΓòÉΓòÉΓòÉΓòÉΓòÉΓòÉΓòÉΓòÉΓòÉΓòÉΓòÉΓòÉΓòÉΓòÉΓòÉΓòÉΓòÉΓòÉΓòÉΓòÉΓòÉΓòÉΓòÉΓòÉΓòÉΓòÉΓòÉΓòÉΓòÉΓòÉΓòÉΓòÉΓòÉΓòÉΓòÉΓòÉΓòÉΓòÉΓòÉΓòÉΓòÉΓòÉΓòÉΓòÉΓòÉΓòÉΓòÉΓòÉΓòÉ
//  MAIN LOOP  (~30 Hz)
// ΓòÉΓòÉΓòÉΓòÉΓòÉΓòÉΓòÉΓòÉΓòÉΓòÉΓòÉΓòÉΓòÉΓòÉΓòÉΓòÉΓòÉΓòÉΓòÉΓòÉΓòÉΓòÉΓòÉΓòÉΓòÉΓòÉΓòÉΓòÉΓòÉΓòÉΓòÉΓòÉΓòÉΓòÉΓòÉΓòÉΓòÉΓòÉΓòÉΓòÉΓòÉΓòÉΓòÉΓòÉΓòÉΓòÉΓòÉΓòÉΓòÉΓòÉΓòÉ
void loop() {
  unsigned long now = millis();
  frame++;

  // ΓöÇΓöÇ IMU ΓöÇΓöÇΓöÇΓöÇΓöÇΓöÇΓöÇΓöÇΓöÇΓöÇΓöÇΓöÇΓöÇΓöÇΓöÇΓöÇΓöÇΓöÇΓöÇΓöÇΓöÇΓöÇΓöÇΓöÇΓöÇΓöÇΓöÇΓöÇΓöÇΓöÇΓöÇΓöÇΓöÇΓöÇΓöÇΓöÇΓöÇΓöÇΓöÇΓöÇΓöÇΓöÇ
  int ev = evIMU();
  if(ev > 0){ escalate(ev); lastEvt = now; }
  deEscalate();
  quietMs = now - lastEvt;

  // ΓöÇΓöÇ Lerp face params ΓöÇΓöÇΓöÇΓöÇΓöÇΓöÇΓöÇΓöÇΓöÇΓöÇΓöÇΓöÇΓöÇΓöÇΓöÇΓöÇΓöÇΓöÇΓöÇΓöÇΓöÇΓöÇΓöÇΓöÇΓöÇΓöÇΓöÇΓöÇΓöÇ
  const FP& t = tgt[(int)mood];
  cur.eyeOpen  = lerp(cur.eyeOpen,  t.eyeOpen,  LERP_SPEED);
  cur.browAngle= lerp(cur.browAngle,t.browAngle, LERP_SPEED);
  cur.browH    = lerp(cur.browH,    t.browH,     LERP_SPEED);
  cur.pupilX   = lerp(cur.pupilX,   t.pupilX,    LERP_SPEED);
  cur.pupilY   = lerp(cur.pupilY,   t.pupilY,    LERP_SPEED);
  cur.mouth    = lerp(cur.mouth,    t.mouth,      LERP_SPEED);

  // ΓöÇΓöÇ Screen flash on mood change ΓöÇΓöÇΓöÇΓöÇΓöÇΓöÇΓöÇΓöÇΓöÇΓöÇΓöÇΓöÇΓöÇΓöÇΓöÇΓöÇΓöÇΓöÇΓöÇ
  if(flashing && now - flashMs < 80) {
    tft.fillRect(0, FA_Y, SW, FA_H, flashCol);
    return;
  } else if(flashing) {
    flashing = false;
    drawAll();
    startInsult(mood);
  }

  // ΓöÇΓöÇ Shake (FURIOUS) ΓöÇΓöÇΓöÇΓöÇΓöÇΓöÇΓöÇΓöÇΓöÇΓöÇΓöÇΓöÇΓöÇΓöÇΓöÇΓöÇΓöÇΓöÇΓöÇΓöÇΓöÇΓöÇΓöÇΓöÇΓöÇΓöÇΓöÇΓöÇΓöÇΓöÇΓöÇ
  if(mood==FURIOUS && now-shakeMs > SHAKE_SPD) {
    shX = random(-3,4); shY = random(-3,4);
    shakeMs = now;
  } else if(mood!=FURIOUS){ shX=0; shY=0; }

  // ΓöÇΓöÇ CALM breathing ΓöÇΓöÇΓöÇΓöÇΓöÇΓöÇΓöÇΓöÇΓöÇΓöÇΓöÇΓöÇΓöÇΓöÇΓöÇΓöÇΓöÇΓöÇΓöÇΓöÇΓöÇΓöÇΓöÇΓöÇΓöÇΓöÇΓöÇΓöÇΓöÇΓöÇΓöÇ
  float breathR = FR;
  if(mood==CALM) breathR = FR + sinf(frame*0.08f)*2.0f;

  // ΓöÇΓöÇ Draw face area ΓöÇΓöÇΓöÇΓöÇΓöÇΓöÇΓöÇΓöÇΓöÇΓöÇΓöÇΓöÇΓöÇΓöÇΓöÇΓöÇΓöÇΓöÇΓöÇΓöÇΓöÇΓöÇΓöÇΓöÇΓöÇΓöÇΓöÇΓöÇΓöÇΓöÇΓöÇ
  drawBG(shX, shY);

  // Effects behind face
  if(mood==FURIOUS) drawFxFurious(FCX+shX, FCY+shY);

  // Draw face circle
  {
    int cx = FCX+shX, cy = FCY+shY;
    int r  = (int)breathR;
    tft.fillCircle(cx+3, cy+4, r, C_SHAD);    // shadow
    tft.fillCircle(cx,   cy,   r, C_FACE);    // face
    tft.drawCircle(cx,   cy,   r, C_BLK);
    tft.drawCircle(cx,   cy, r+1, C_BLK);

    drawBrows(cx,cy);
    drawEyes(cx,cy);
    drawMouth(cx,cy);

    // Mood-specific overlaid effects
    if(mood==CALM)    drawFxCalm(cx,cy);
    if(mood==ANNOYED) drawFxAnnoyed(cx,cy);
    if(mood==SULKING) drawFxSulking(cx,cy);
  }

  // Border lightning (FURIOUS, in the face area)
  if(mood==FURIOUS && now-lgtMs > LGT_SPD) {
    lgtOn = !lgtOn; lgtMs = now;
    if(lgtOn) drawLightning();
  }

  // ΓöÇΓöÇ Top bar updates ΓöÇΓöÇΓöÇΓöÇΓöÇΓöÇΓöÇΓöÇΓöÇΓöÇΓöÇΓöÇΓöÇΓöÇΓöÇΓöÇΓöÇΓöÇΓöÇΓöÇΓöÇΓöÇΓöÇΓöÇΓöÇΓöÇΓöÇΓöÇΓöÇΓöÇΓöÇ
  // Rage meter step
  if(ragePct != rageTarget && now-rageMs > RAGE_STEP) {
    ragePct += (ragePct < rageTarget) ? 1 : -1;
    rageMs = now;
  }
  // Heartbeat flash
  if(mood==FURIOUS && now-hbMs > HB_INTERVAL) {
    hbFlash = !hbFlash; hbMs = now;
  } else if(mood!=FURIOUS) hbFlash=false;
  drawRage(ragePct, hbFlash);

  // ΓöÇΓöÇ Blink ΓöÇΓöÇΓöÇΓöÇΓöÇΓöÇΓöÇΓöÇΓöÇΓöÇΓöÇΓöÇΓöÇΓöÇΓöÇΓöÇΓöÇΓöÇΓöÇΓöÇΓöÇΓöÇΓöÇΓöÇΓöÇΓöÇΓöÇΓöÇΓöÇΓöÇΓöÇΓöÇΓöÇΓöÇΓöÇΓöÇΓöÇΓöÇΓöÇΓöÇΓöÇ
  if(!blinking && now >= blinkAt) {
    blinking = true; blinkMs = now;
    blinkAt  = now + random(3000,7000);
  }
  if(blinking && now-blinkMs > BLINK_DUR) {
    blinking = false;
  }

  // ΓöÇΓöÇ Typewriter ΓöÇΓöÇΓöÇΓöÇΓöÇΓöÇΓöÇΓöÇΓöÇΓöÇΓöÇΓöÇΓöÇΓöÇΓöÇΓöÇΓöÇΓöÇΓöÇΓöÇΓöÇΓöÇΓöÇΓöÇΓöÇΓöÇΓöÇΓöÇΓöÇΓöÇΓöÇΓöÇΓöÇΓöÇΓöÇ
  if(revealed < strlen(insultBuf) && now-twMs > TW_SPD) {
    revealed++; twMs = now;
    drawInsultText(revealed);
  }

  // ΓöÇΓöÇ LED blink ΓöÇΓöÇΓöÇΓöÇΓöÇΓöÇΓöÇΓöÇΓöÇΓöÇΓöÇΓöÇΓöÇΓöÇΓöÇΓöÇΓöÇΓöÇΓöÇΓöÇΓöÇΓöÇΓöÇΓöÇΓöÇΓöÇΓöÇΓöÇΓöÇΓöÇΓöÇΓöÇΓöÇΓöÇΓöÇΓöÇ
  if((mood==FURIOUS||mood==SULKING) && now-ledMs>450) {
    ledBlink=!ledBlink; digitalWrite(LED_G, ledBlink?HIGH:LOW);
    ledMs=now;
  }

  // ΓöÇΓöÇ Idle arm twitch ΓöÇΓöÇΓöÇΓöÇΓöÇΓöÇΓöÇΓöÇΓöÇΓöÇΓöÇΓöÇΓöÇΓöÇΓöÇΓöÇΓöÇΓöÇΓöÇΓöÇΓöÇΓöÇΓöÇΓöÇΓöÇΓöÇΓöÇΓöÇΓöÇΓöÇΓöÇ
  if(mood==CALM && now-idleArmMs > IDLE_ARM) {
    armGo(96,90,300); delay(200); armGo(90,90,300);
    buzz(180,60); idleArmMs=now;
  }

  delay(loopMs);
}

// ΓòÉΓòÉΓòÉΓòÉΓòÉΓòÉΓòÉΓòÉΓòÉΓòÉΓòÉΓòÉΓòÉΓòÉΓòÉΓòÉΓòÉΓòÉΓòÉΓòÉΓòÉΓòÉΓòÉΓòÉΓòÉΓòÉΓòÉΓòÉΓòÉΓòÉΓòÉΓòÉΓòÉΓòÉΓòÉΓòÉΓòÉΓòÉΓòÉΓòÉΓòÉΓòÉΓòÉΓòÉΓòÉΓòÉΓòÉΓòÉΓòÉΓòÉΓòÉ
//  BACKGROUND + GRID
// ΓòÉΓòÉΓòÉΓòÉΓòÉΓòÉΓòÉΓòÉΓòÉΓòÉΓòÉΓòÉΓòÉΓòÉΓòÉΓòÉΓòÉΓòÉΓòÉΓòÉΓòÉΓòÉΓòÉΓòÉΓòÉΓòÉΓòÉΓòÉΓòÉΓòÉΓòÉΓòÉΓòÉΓòÉΓòÉΓòÉΓòÉΓòÉΓòÉΓòÉΓòÉΓòÉΓòÉΓòÉΓòÉΓòÉΓòÉΓòÉΓòÉΓòÉΓòÉ
void drawBG(int8_t ox, int8_t oy) {
  uint16_t bg = bgC(mood), gr = grC(mood);
  tft.fillRect(0, FA_Y, SW, FA_H, bg);
  for(int x=8;x<SW;x+=8) tft.drawFastVLine(x+ox, FA_Y, FA_H, gr);
  for(int y=FA_Y+8;y<IB_Y;y+=8) tft.drawFastHLine(0, y+oy, SW, gr);
}

// ΓòÉΓòÉΓòÉΓòÉΓòÉΓòÉΓòÉΓòÉΓòÉΓòÉΓòÉΓòÉΓòÉΓòÉΓòÉΓòÉΓòÉΓòÉΓòÉΓòÉΓòÉΓòÉΓòÉΓòÉΓòÉΓòÉΓòÉΓòÉΓòÉΓòÉΓòÉΓòÉΓòÉΓòÉΓòÉΓòÉΓòÉΓòÉΓòÉΓòÉΓòÉΓòÉΓòÉΓòÉΓòÉΓòÉΓòÉΓòÉΓòÉΓòÉΓòÉ
//  FULL SCREEN REDRAW
// ΓòÉΓòÉΓòÉΓòÉΓòÉΓòÉΓòÉΓòÉΓòÉΓòÉΓòÉΓòÉΓòÉΓòÉΓòÉΓòÉΓòÉΓòÉΓòÉΓòÉΓòÉΓòÉΓòÉΓòÉΓòÉΓòÉΓòÉΓòÉΓòÉΓòÉΓòÉΓòÉΓòÉΓòÉΓòÉΓòÉΓòÉΓòÉΓòÉΓòÉΓòÉΓòÉΓòÉΓòÉΓòÉΓòÉΓòÉΓòÉΓòÉΓòÉΓòÉ
void drawAll() {
  tft.fillScreen(C_BLK);
  drawBG();
  drawTopBar();
  drawInsultBar();
}

// ΓòÉΓòÉΓòÉΓòÉΓòÉΓòÉΓòÉΓòÉΓòÉΓòÉΓòÉΓòÉΓòÉΓòÉΓòÉΓòÉΓòÉΓòÉΓòÉΓòÉΓòÉΓòÉΓòÉΓòÉΓòÉΓòÉΓòÉΓòÉΓòÉΓòÉΓòÉΓòÉΓòÉΓòÉΓòÉΓòÉΓòÉΓòÉΓòÉΓòÉΓòÉΓòÉΓòÉΓòÉΓòÉΓòÉΓòÉΓòÉΓòÉΓòÉΓòÉ
//  TOP BAR
// ΓòÉΓòÉΓòÉΓòÉΓòÉΓòÉΓòÉΓòÉΓòÉΓòÉΓòÉΓòÉΓòÉΓòÉΓòÉΓòÉΓòÉΓòÉΓòÉΓòÉΓòÉΓòÉΓòÉΓòÉΓòÉΓòÉΓòÉΓòÉΓòÉΓòÉΓòÉΓòÉΓòÉΓòÉΓòÉΓòÉΓòÉΓòÉΓòÉΓòÉΓòÉΓòÉΓòÉΓòÉΓòÉΓòÉΓòÉΓòÉΓòÉΓòÉΓòÉ
void drawTopBar() {
  tft.fillRect(0,0,SW,TB_H,C_BARBG);
  tft.drawFastHLine(0,TB_H-1,SW,C_BRBRD);
  tft.setTextSize(1); tft.setTextColor(C_WHT);
  tft.setCursor(2,2); tft.print("MOOD:");
  tft.setTextColor(tcC(mood));
  tft.setCursor(34,2); tft.print(moodStr(mood));
  drawRage(ragePct, false);
}

// ΓòÉΓòÉΓòÉΓòÉΓòÉΓòÉΓòÉΓòÉΓòÉΓòÉΓòÉΓòÉΓòÉΓòÉΓòÉΓòÉΓòÉΓòÉΓòÉΓòÉΓòÉΓòÉΓòÉΓòÉΓòÉΓòÉΓòÉΓòÉΓòÉΓòÉΓòÉΓòÉΓòÉΓòÉΓòÉΓòÉΓòÉΓòÉΓòÉΓòÉΓòÉΓòÉΓòÉΓòÉΓòÉΓòÉΓòÉΓòÉΓòÉΓòÉΓòÉ
//  RAGE METER  (10 segments + heartbeat pulse)
// ΓòÉΓòÉΓòÉΓòÉΓòÉΓòÉΓòÉΓòÉΓòÉΓòÉΓòÉΓòÉΓòÉΓòÉΓòÉΓòÉΓòÉΓòÉΓòÉΓòÉΓòÉΓòÉΓòÉΓòÉΓòÉΓòÉΓòÉΓòÉΓòÉΓòÉΓòÉΓòÉΓòÉΓòÉΓòÉΓòÉΓòÉΓòÉΓòÉΓòÉΓòÉΓòÉΓòÉΓòÉΓòÉΓòÉΓòÉΓòÉΓòÉΓòÉΓòÉ
void drawRage(uint8_t pct, bool hb) {
  int bx=90, by=2, bw=48, bh=8;
  tft.drawRect(bx-1,by-1,bw+2,bh+2,C_BRBRD);
  tft.fillRect(bx,by,bw,bh,C_BARBG);

  uint16_t rc = rcC(mood);
  uint8_t segs = (pct*10)/100 + (hb?1:0);
  segs = min(segs,(uint8_t)10);
  for(int i=0;i<10;i++) {
    if(i<segs) tft.fillRect(bx+i*4+1,by+1,3,bh-2,rc);
  }
  // % text
  tft.fillRect(bx+bw+2,by,26,bh,C_BARBG);
  tft.setTextSize(1); tft.setTextColor(rc);
  tft.setCursor(bx+bw+1,by+1);
  char pb[5]; snprintf(pb,5,"%3d%%",pct); tft.print(pb);
}

// ΓòÉΓòÉΓòÉΓòÉΓòÉΓòÉΓòÉΓòÉΓòÉΓòÉΓòÉΓòÉΓòÉΓòÉΓòÉΓòÉΓòÉΓòÉΓòÉΓòÉΓòÉΓòÉΓòÉΓòÉΓòÉΓòÉΓòÉΓòÉΓòÉΓòÉΓòÉΓòÉΓòÉΓòÉΓòÉΓòÉΓòÉΓòÉΓòÉΓòÉΓòÉΓòÉΓòÉΓòÉΓòÉΓòÉΓòÉΓòÉΓòÉΓòÉΓòÉ
//  INSULT BAR  (chrome only)
// ΓòÉΓòÉΓòÉΓòÉΓòÉΓòÉΓòÉΓòÉΓòÉΓòÉΓòÉΓòÉΓòÉΓòÉΓòÉΓòÉΓòÉΓòÉΓòÉΓòÉΓòÉΓòÉΓòÉΓòÉΓòÉΓòÉΓòÉΓòÉΓòÉΓòÉΓòÉΓòÉΓòÉΓòÉΓòÉΓòÉΓòÉΓòÉΓòÉΓòÉΓòÉΓòÉΓòÉΓòÉΓòÉΓòÉΓòÉΓòÉΓòÉΓòÉΓòÉ
void drawInsultBar() {
  tft.fillRect(0,IB_Y,SW,SH-IB_Y,C_BARBG);
  tft.drawFastHLine(0,IB_Y,SW,C_BRBRD);
  tft.drawFastHLine(0,SH-1,SW,C_BRBRD);
  // Decorative arrows
  tft.setTextColor(C_BRBRD); tft.setTextSize(1);
  tft.setCursor(2,IB_Y+6);  tft.print("-=");
  tft.setCursor(140,IB_Y+6);tft.print("=-");
}
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

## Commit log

2026-09-05 Add hateu_pod.scad with flattened mating surfaces and optimized print layout
    [hateu_pod.scad]
2026-09-05 Add robot face animator v1.0: ESP8266+ST7735 procedural face with 11 expressions, spring physics, gaze engine, blink engine, micro-animations
2026-09-05 Fix pin wiring to match actual hardware: TFT CS->D3/GPIO0, DC->D4/GPIO2; add all component pin defines
2026-09-05 Migrate Hatebot to ESP8266+ST7735: combine aesthetic spring physics face renderer with full mood machine, IMU, servos, and HUD
2026-09-05 Lower IMU thresholds to increase sensitivity for taps, shakes, and tilts
2026-09-05 Cleanup: remove old ESP32 code and prototype, keep only the final ESP8266 merged firmware as the main hatebot project
2026-09-05 Fix Arduino IDE compilation error by adding explicit function prototypes for the Mood enum
    [hatebot.ino]
2026-09-05 Revert face rendering back to V3 style scaled for ESP8266 and fix MPU initialization
    [hatebot.ino]
2026-09-05 Fix servos: use default attach without hardcoded pulse widths for ESP8266 compatibility
    [hatebot.ino]
2026-09-05 Lower IMU thresholds to make bot highly sensitive to small shakes
2026-09-05 Optimize IMU thresholds using math derived from user's raw shaking data
2026-09-05 Update README: ESP8266 migration, mermaid schematics, team contributions, and UI mockup
2026-09-05 Add physical schematic and final build photos to README
